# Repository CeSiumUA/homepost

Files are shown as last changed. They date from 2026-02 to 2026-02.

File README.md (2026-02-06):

# Homepost

Homepost is an ESP32-based home monitoring and automation hub that combines BLE tracking, environmental sensing, radiation monitoring, and MQTT integration into a single device.

## Features

- **BLE iBeacon Tracking**: Detects and tracks iBeacon devices for presence detection (e.g., phone tracking)
- **HTU21 Temperature & Humidity Sensor**: Monitors environmental conditions via I2C and publishes data via MQTT
- **Geiger Counter Integration**: Monitors radiation levels and publishes data via MQTT
- **WiFi Connectivity**:
  - Station mode for connecting to existing networks
  - SoftAP mode for initial configuration
  - Automatic reconnection with configurable retry intervals
- **HTTP Server**: Web-based configuration interface
- **MQTT Publishing**: Sends sensor data and presence information to an MQTT broker
- **NVS Storage**: Persistent storage for WiFi credentials, MQTT settings, and configuration

## Hardware Requirements

- ESP32 development board (4MB flash minimum)
- HTU21D temperature/humidity sensor (I2C, default: SDA=GPIO21, SCL=GPIO22)
- Geiger counter sensor (connected via GPIO)
- Power supply (USB or external)

> **Note**: A custom PCB design is available in the `hardware/` directory (KiCad 8 format).

## Software Dependencies

- ESP-IDF v5.5 or later
- FreeRTOS (included with ESP-IDF)

## Building the Project

### Prerequisites

1. Install ESP-IDF following the [official installation guide](https://docs.espressif.com/projects/esp-idf/en/latest/esp32/get-started/index.html)
2. Set up the ESP-IDF environment:

   ```bash
   . $HOME/esp/esp-idf/export.sh
   ```

### Configure

Configure the project using menuconfig:

```bash
idf.py menuconfig
```

Navigate to `homepost configuration` to customize:

- **BT Options**: Bluetooth device name, inquiry length
- **Scanner Options**: RSSI filters, iBeacon major/minor IDs, scan timeout
- **WiFi Configuration**: SoftAP credentials, reconnection settings
- **HTTP Server Configuration**: Port settings
- **Storage Configuration**: NVS keys for credentials

### Build

Build the project:

```bash
idf.py build
```

### Flash

Flash the firmware to your ESP32:

```bash
idf.py -p PORT flash
```

Replace `PORT` with your ESP32's serial port (e.g., `COM3` on Windows or `/dev/ttyUSB0` on Linux).

### Monitor

View the serial output:

```bash
idf.py -p PORT monitor
```

Or combine flash and monitor:

```bash
idf.py -p PORT flash monitor
```

## Configuration

### Initial Setup

1. On first boot, the device will create a WiFi access point named `HOMEPOST` (default password: `12345678`)
2. Connect to this network and access the web interface at `http://192.168.4.1`
3. Configure:
   - WiFi credentials for your home network
   - MQTT broker settings (address, port, credentials)
   - MQTT topic base (runtime configurable via web interface)
   - iBeacon tracking parameters
   - Publish intervals

### iBeacon Tracking

Configure the iBeacon major and minor IDs to match the devices you want to track:

- `HOMEPOST_SCAN_MAJOR_FILTER`: Major ID (default: 100)
- `HOMEPOST_SCAN_MINOR_FILTER`: Minor ID (default: 40004)
- `HOMEPOST_SCAN_TIMEOUT_MINUTES`: How long to wait before marking device as absent (default: 2 minutes)

### MQTT Topics

The device publishes to topics under the configured base topic:

- `{topic}/homepost_version`: Firmware version in JSON format (`{"version": "X.Y.Z"}`), published on MQTT connection
- `{topic}/phone_present`: Presence detection status (iBeacon tracking)
- `{topic}/phone_rssi`: BLE RSSI signal strength in JSON format (`{"rssi": -XX}`) when device is present
- `{topic}/temperature`: Temperature readings in JSON format (`{"temperature": XX.XX}`)
- `{topic}/humidity`: Humidity readings in JSON format (`{"humidity": XX.XX}`)
- `{topic}/geiger`: Geiger counter CPM (counts per minute) data

### HTU21 Temperature & Humidity Sensor

Configure the HTU21 sensor via menuconfig:

- `HOMEPOST_HTU21_TIMER_PERIOD_MS`: Reading interval (default: 60000ms / 1 minute)
- `HOMEPOST_HTU21_I2C_SDA_GPIO`: I2C SDA pin (default: GPIO 21)
- `HOMEPOST_HTU21_I2C_SCL_GPIO`: I2C SCL pin (default: GPIO 22)
- `HOMEPOST_HTU21_I2C_FREQ_HZ`: I2C clock frequency (default: 100kHz)

## Project Structure

```text
homepost/
├── CMakeLists.txt              # Project configuration
├── sdkconfig                   # Build configuration
├── main/
│   ├── main.c                  # Application entry point
│   ├── wifi.c                  # WiFi connection management
│   ├── http_server.c           # Web configuration interface
│   ├── ble_scanner.c           # BLE scanning functionality
│   ├── ble_ibeacon.c           # iBeacon protocol handling
│   ├── tracker_scanner.c       # Presence tracking logic
│   ├── geiger_counter.c        # Radiation sensor integration
│   ├── htu21_sensor.c          # HTU21 temperature/humidity sensor
│   ├── mqtt_connection.c       # MQTT client
│   ├── internal_storage.c      # NVS storage management
│   ├── ota_update.c            # OTA firmware update
│   └── Kconfig.projbuild       # Configuration menu
├── inc/                        # Header files
└── hardware/                   # KiCad PCB design files
    └── manufacturing/          # Gerber files for PCB fabrication
```

## OTA (Over-The-Air) Updates

Homepost supports automatic firmware updates from GitHub releases.

### Requirements

1. **Flash Size**: Requires 4MB flash (configured in `menuconfig` → `Serial flasher config` → `Flash size`)

2. **Partition Table**: Must use OTA-compatible partition layout. In `menuconfig`:
   - Navigate to `Partition Table`
   - Select `Two large size OTA partitions` (required for 4MB flash with OTA)

3. **Bootloader Rollback** (recommended): Enable automatic rollback on failed boot:
   - Navigate to `Bootloader config`
   - Enable `CONFIG_BOOTLOADER_APP_ROLLBACK_ENABLE`

### GitHub Release Format

When creating releases on GitHub:

- **Tag format**: `release-v{version}` (e.g., `release-v1.3.0`)
- **Asset filename**: `homepost-{version}.bin` (e.g., `homepost-1.3.0.bin`)

### OTA Configuration

Configure OTA settings via `menuconfig` → `homepost configuration` → `OTA Update Configuration`:

- `HOMEPOST_OTA_ENABLED`: Enable/disable OTA updates (default: enabled)
- `HOMEPOST_OTA_GITHUB_OWNER`: GitHub repository owner/organization
- `HOMEPOST_OTA_GITHUB_REPO`: Repository name (default: `homepost`)
- `HOMEPOST_OTA_CHECK_INTERVAL_HOURS`: Update check interval (default: 4 hours)
- `HOMEPOST_OTA_INITIAL_DELAY_SECONDS`: Delay before first check (default: 30 seconds)

### Manual Update

Access the web interface and use the "Firmware Update" section to:

- View current and available versions
- Check for updates manually
- Trigger an update installation

### API Endpoints

- `GET /check-update`: Returns JSON with version info
- `POST /trigger-update`: Triggers immediate update check and installation

## Hardware Design

The `hardware/` directory contains a complete KiCad 8 project for a custom Homepost PCB:

- **Schematic**: `homepost.kicad_sch`
- **PCB Layout**: `homepost.kicad_pcb`
- **Manufacturing Files**: `manufacturing/` directory contains Gerber files and drill files ready for PCB fabrication

## Troubleshooting

### WiFi Connection Issues

- Check the serial monitor for connection status
- Verify credentials are correct via the web interface
- The device will retry connection every 3 minutes by default

### MQTT Connection Problems

- Verify broker address and port are correct
- Check firewall settings on the broker
- Ensure credentials (if required) are properly configured

### BLE Scanning Not Working

- Verify the iBeacon major/minor IDs match your tracking device
- Check RSSI threshold if filtering is enabled
- Ensure Bluetooth (BLE advertising) is enabled on the tracking device

### HTU21 Sensor Not Working

- Verify I2C wiring: SDA to GPIO21, SCL to GPIO22 (default pins)
- Check that the sensor is powered (3.3V)
- Review serial monitor for I2C initialization errors
- Ensure no I2C address conflicts (HTU21 uses address 0x40)

## License

This project is provided as-is for personal and educational use.

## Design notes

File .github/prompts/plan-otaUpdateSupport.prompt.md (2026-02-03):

## Plan: Add OTA Update Support via GitHub Releases

Enable the ESP32 device to automatically check for firmware updates on GitHub releases, download newer versions over HTTPS, and self-update using ESP-IDF's native OTA capabilities. Firmware assets follow naming `homepost-{version}.bin`, tags follow `release-v{version}` format.

### Steps

1. **Switch partition table to OTA-compatible layout** in `menuconfig` → Partition Table → select "Factory app, two OTA definitions", and enable `CONFIG_BOOTLOADER_APP_ROLLBACK_ENABLE` under Bootloader config for automatic rollback on failed boot.

2. **Create [main/ota_update.c](main/ota_update.c) and [inc/ota_update.h](inc/ota_update.h)** implementing a FreeRTOS task that:
   - Waits 30 seconds after start for network stability, then waits for WiFi via `wifi_is_connected_to_internet()`
   - Fetches `https://api.github.com/repos/{owner}/{repo}/releases/latest` using `esp_http_client`
   - Parses JSON with `cJSON`: extracts `tag_name`, strips `release-v` prefix to get version (e.g., `release-v1.2.0` → `1.2.0`)
   - Finds asset URL matching `homepost-{version}.bin` from `assets[].browser_download_url`
   - Compares semver against `CONFIG_APP_PROJECT_VER`
   - On newer version: calls `tracker_scanner_stop()` to free heap, runs `esp_https_ota()` with `esp_crt_bundle_attach()` for GitHub's CA chain, then `esp_restart()`
   - Loops with `CONFIG_HOMEPOST_OTA_CHECK_INTERVAL_HOURS` delay (default 4 hours)

3. **Add OTA Kconfig options** in [main/Kconfig.projbuild](main/Kconfig.projbuild):
   - `CONFIG_HOMEPOST_OTA_ENABLED` (bool, default y)
   - `CONFIG_HOMEPOST_OTA_GITHUB_OWNER` (string)
   - `CONFIG_HOMEPOST_OTA_GITHUB_REPO` (string, default "homepost")
   - `CONFIG_HOMEPOST_OTA_CHECK_INTERVAL_HOURS` (int, default 4)
   - `CONFIG_HOMEPOST_OTA_INITIAL_DELAY_SECONDS` (int, default 30)
   
   Add required components to REQUIRES in [main/CMakeLists.txt](main/CMakeLists.txt): `esp_https_ota`, `esp_http_client`, `app_update`, `esp_crt_bundle`, `json`

4. **Integrate OTA task startup** in [main/main.c](main/main.c) by calling `ota_update_start_task()` after WiFi initialization, guarded by `#if CONFIG_HOMEPOST_OTA_ENABLED`, following existing task patterns with `configASSERT()`.

5. **Add HTTP endpoints** in [main/http_server.c](main/http_server.c):
   - `GET /check-update` → returns JSON `{"current_version": "1.2.0", "available_version": "1.2.1", "update_available": true}`
   - `POST /trigger-update` → stops BLE tracking, triggers immediate OTA, restarts on success
   - Update [main/web/index.html](main/web/index.html) with version display and "Check for Updates" button

6. **Update documentation**: Add OTA section to [README.md](README.md) explaining GitHub release requirements (tag format `release-v{version}`, asset naming `homepost-{version}.bin`), Kconfig options, rollback behavior. Update [.github/copilot-instructions.md](.github/copilot-instructions.md) with OTA architecture. Bump `CONFIG_APP_PROJECT_VER` in [sdkconfig](sdkconfig).

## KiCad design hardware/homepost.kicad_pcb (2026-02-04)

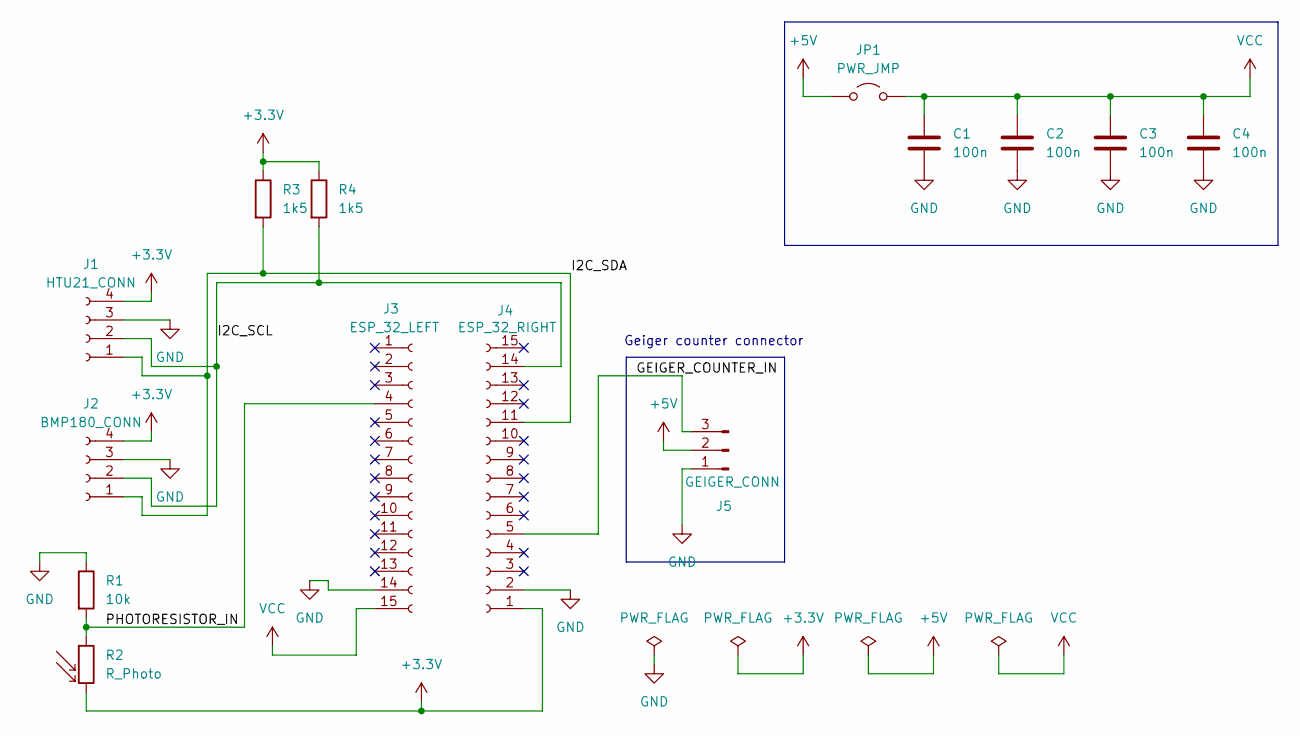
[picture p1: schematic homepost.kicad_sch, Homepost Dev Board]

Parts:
C1, C2, C3, C4: 100n; C_0402_1005Metric
J1: HTU21_CONN; PinSocket_1x04_P2.54mm_Vertical
J2: BMP180_CONN; PinSocket_1x04_P2.54mm_Vertical
J3: ESP_32_LEFT; PinSocket_1x15_P2.54mm_Vertical
J4: ESP_32_RIGHT; PinSocket_1x15_P2.54mm_Vertical
J5: GEIGER_CONN; PinHeader_1x03_P2.54mm_Vertical
JP1: PWR_JMP; PinHeader_1x02_P2.54mm_Vertical
R1: 10k; R_Axial_DIN0204_L3.6mm_D1.6mm_P5.08mm_Horizontal
R2: R_Photo; R_Axial_DIN0204_L3.6mm_D1.6mm_P5.08mm_Horizontal
R3, R4: 1k5; R_0402_1005Metric

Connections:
+3.3V: J1.4, J2.4, J4.1, R2.2, R3.1, R4.1
+5V: J5.2, JP1.1 (A)
/GEIGER_COUNTER_IN: J4.5, J5.3
/I2C_SCL: J1.2, J2.2, J4.14, R4.2
/I2C_SDA: J1.1, J2.1, J4.11, R3.2
/PHOTORESISTOR_IN: J3.4, R1.2, R2.1
GND: C1.2, C2.2, C3.2, C4.2, J1.3, J2.3, J3.14, J4.2, J5.1, R1.1
VCC: C1.1, C2.1, C3.1, C4.1, J3.15, JP1.2 (B)

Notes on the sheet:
Geiger counter connector

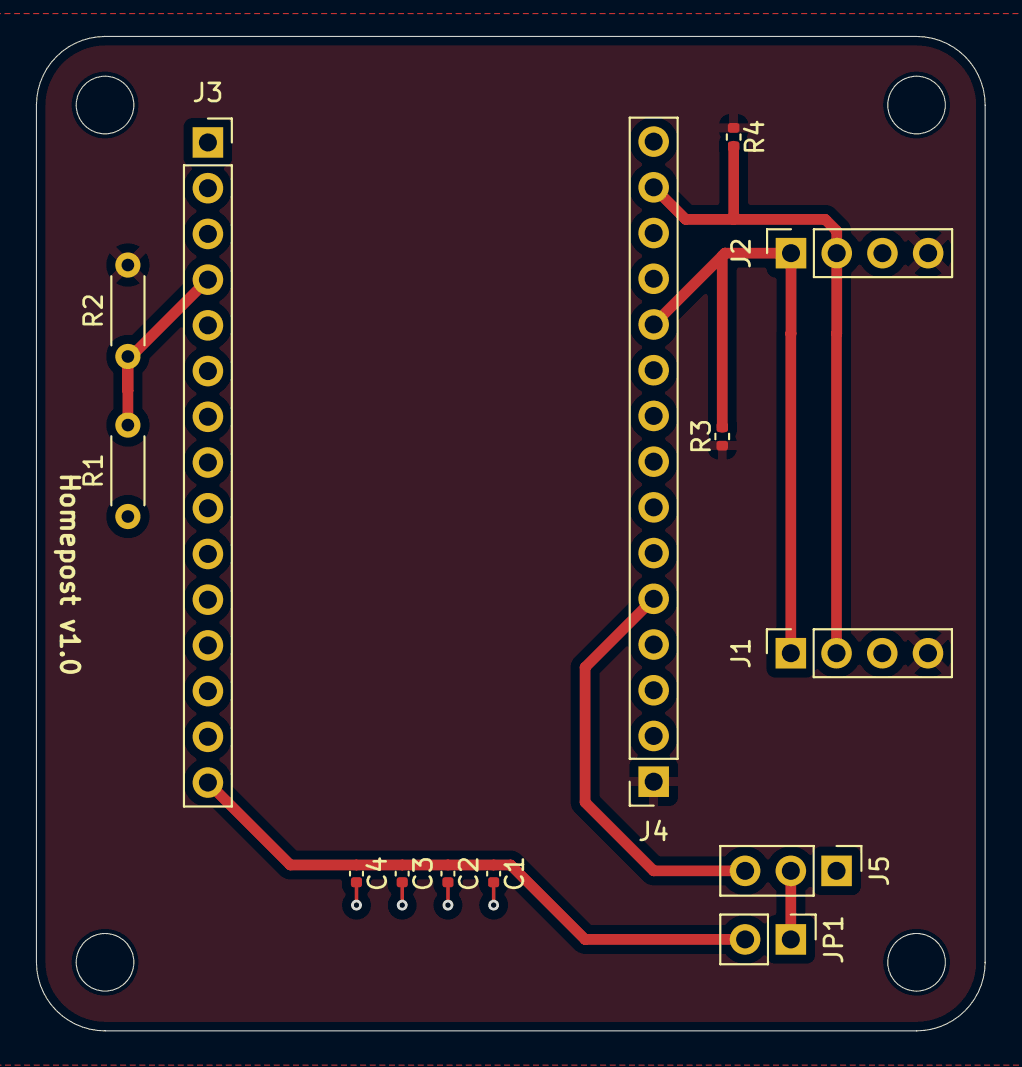
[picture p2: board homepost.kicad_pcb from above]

Board: 2 copper layers, 52.7 x 55.2 mm, 14 parts (0 on the bottom side), 8 nets.

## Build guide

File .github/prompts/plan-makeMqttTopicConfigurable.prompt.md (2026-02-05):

## Plan: Make MQTT Topic Runtime Configurable

Move MQTT topic from compile-time Kconfig to runtime configuration via web interface and NVS storage. The NVS storage functions already exist—main work involves updating the web form, HTTP handler with validation, and refactoring all components to build topic strings dynamically at initialization time.

### Steps

1. **Add MQTT topic input field** to [main/web/index.html](main/web/index.html) within the MQTT configuration form — simple text input named `mqtt-topic`, no default value display needed.

2. **Update POST handler** in [http_server.c](main/http_server.c) `mqtt_setup_post_handler` to parse `mqtt-topic` field, validate it (reject empty strings, check for invalid MQTT wildcard characters `+` and `#`), and call existing `internal_storage_save_mqtt_topic()`. Return HTTP 400 with error message if validation fails.

3. **Add topic provider function** in [mqtt_connection.c](main/mqtt_connection.c) — create `mqtt_connection_get_base_topic(char *topic_out)` that loads from NVS via `internal_storage_get_mqtt_topic()`, falling back to `CONFIG_HOMEPOST_MQTT_TOPIC` if not preserved. Expose via [mqtt_connection.h](inc/mqtt_connection.h).

4. **Refactor [mqtt_connection.c](main/mqtt_connection.c)** — change `version_message` topic from static literal to a 100-byte static buffer, populate via `snprintf(buf, size, "%s/homepost_version", base_topic)` in `mqtt_connection_publish_version()` before first use.

5. **Refactor [tracker_scanner.c](main/tracker_scanner.c)** — add static topic buffer, build `"{base}/phone_present"` in `tracker_scanner_start_task()` before publishing.

6. **Refactor [htu21_sensor.c](main/htu21_sensor.c)** — add static buffers for temperature and humidity topics, build `"{base}/temperature"` and `"{base}/humidity"` in `htu21_sensor_start()`.

7. **Refactor [geiger_counter.c](main/geiger_counter.c)** — add static topic buffer, build `"{base}/radiation"` in `geiger_counter_start()`.

8. **Update documentation** in [README.md](README.md) and [.github/copilot-instructions.md](.github/copilot-instructions.md) to note MQTT topic is now runtime-configurable via web interface.

9. **Bump version** in [sdkconfig](sdkconfig) `CONFIG_APP_PROJECT_VER`. Bump just a patch version, don't change major/minor.

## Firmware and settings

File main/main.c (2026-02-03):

#include <stdio.h>
#include "internal_storage.h"
#include "tracker_scanner.h"
#include "wifi.h"
#include "http_server.h"
#include "geiger_counter.h"
#include "htu21_sensor.h"
#include "esp_log.h"
#include <esp_timer.h>

#if CONFIG_HOMEPOST_OTA_ENABLED
#include "ota_update.h"
#endif

static void wifi_reconnection_timer_cb(void *arg);

static esp_timer_handle_t wifi_reconnection_timer;

static const esp_timer_create_args_t wifi_reconnection_timer_args = {
    .callback = &wifi_reconnection_timer_cb,
};

static const char *TAG = __FILE__;

static void wifi_reconnection_timer_cb(void *arg)
{
    bool reconnection_succeeded = false;
    reconnection_succeeded = wifi_connect_sta(false);
    if(reconnection_succeeded){
        ESP_LOGI(TAG, "WiFi reconnection succeeded");
        esp_timer_stop(wifi_reconnection_timer);
    }
    else{
        ESP_LOGI(TAG, "WiFi reconnection failed");
    }
}

void app_main(void)
{
    bool connected_to_ap = false;
    internal_storage_init();

    wifi_init();

    if(internal_storage_check_wifi_credentials_preserved()){
        connected_to_ap = wifi_connect_sta(false);
        if (!connected_to_ap){
            ESP_LOGI(TAG, "WiFi connection failed, starting reconnection timer");
            esp_timer_create(&wifi_reconnection_timer_args, &wifi_reconnection_timer);
            esp_timer_start_periodic(wifi_reconnection_timer, CONFIG_HOMEPOST_WIFI_RECONNECTION_TIMER_PERIOD_US);
        }
        else{
            ESP_LOGI(TAG, "WiFi connection succeeded");
        }
    }
    
    if(!connected_to_ap){
        ESP_LOGI(TAG, "WiFi credentials not found in NVS, starting softAP mode");
        wifi_start_softap();
    }

    http_server_init();
    http_server_start();

    tracker_scanner_start_task();
    mqtt_connection_start_task();
    geiger_counter_start();
    htu21_sensor_start();

#if CONFIG_HOMEPOST_OTA_ENABLED
    ota_update_start_task();
#endif
}

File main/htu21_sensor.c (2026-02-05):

#include "htu21_sensor.h"
#include "mqtt_connection.h"
#include <driver/i2c_master.h>
#include <esp_timer.h>
#include <esp_log.h>
#include <string.h>
#include <freertos/FreeRTOS.h>
#include <freertos/task.h>

#define HTU21_I2C_ADDR                  0x40
#define HTU21_CMD_TEMP_HOLD             0xE3
#define HTU21_CMD_HUMIDITY_HOLD         0xE5
#define HTU21_CMD_TEMP_NOHOLD           0xF3
#define HTU21_CMD_HUMIDITY_NOHOLD       0xF5
#define HTU21_CMD_SOFT_RESET            0xFE

static const char *TAG = __FILE__;

static i2c_master_bus_handle_t i2c_bus_handle = NULL;
static i2c_master_dev_handle_t htu21_dev_handle = NULL;

static esp_timer_handle_t htu21_timer;

static char temperature_payload[32];
static char humidity_payload[32];
static char temperature_topic[100];
static char humidity_topic[100];

static struct mqtt_connection_message_t temperature_message = {
    .topic = temperature_topic,
    .payload = temperature_payload,
    .qos = 0
};

static struct mqtt_connection_message_t humidity_message = {
    .topic = humidity_topic,
    .payload = humidity_payload,
    .qos = 0
};

static esp_err_t htu21_read_temperature(float *temperature)
{
    uint8_t cmd = HTU21_CMD_TEMP_NOHOLD;
    uint8_t data[2];
    esp_err_t ret;

    ret = i2c_master_transmit(htu21_dev_handle, &cmd, 1, 1000);
    if (ret != ESP_OK) {
        ESP_LOGE(TAG, "Failed to send temperature command: %s", esp_err_to_name(ret));
        return ret;
    }

    vTaskDelay(pdMS_TO_TICKS(85));

    ret = i2c_master_receive(htu21_dev_handle, data, sizeof(data), 1000);
    if (ret != ESP_OK) {
        ESP_LOGE(TAG, "Failed to receive temperature data: %s", esp_err_to_name(ret));
        return ret;
    }

    uint16_t raw_temp = (data[0] << 8) | data[1];
    *temperature = -46.85 + 175.72 * (raw_temp / 65536.0);

    return ESP_OK;
}

static esp_err_t htu21_read_humidity(float *humidity)
{
    uint8_t cmd = HTU21_CMD_HUMIDITY_NOHOLD;
    uint8_t data[2];
    esp_err_t ret;

    ret = i2c_master_transmit(htu21_dev_handle, &cmd, 1, 1000);
    if (ret != ESP_OK) {
        ESP_LOGE(TAG, "Failed to send humidity command: %s", esp_err_to_name(ret));
        return ret;
    }

    vTaskDelay(pdMS_TO_TICKS(50));

    ret = i2c_master_receive(htu21_dev_handle, data, sizeof(data), 1000);
    if (ret != ESP_OK) {
        ESP_LOGE(TAG, "Failed to receive humidity data: %s", esp_err_to_name(ret));
        return ret;
    }

    uint16_t raw_humidity = (data[0] << 8) | data[1];
    *humidity = -6.0 + 125.0 * (raw_humidity / 65536.0);

    return ESP_OK;
}

static void htu21_timer_cb(void *arg)
{
    float temperature, humidity;
    esp_err_t ret;

    ret = htu21_read_temperature(&temperature);
    if (ret == ESP_OK) {
        ESP_LOGI(TAG, "Temperature: %.2f C", temperature);
        memset(temperature_payload, 0, sizeof(temperature_payload));
        int len = snprintf(temperature_payload, sizeof(temperature_payload), 
                          "{\"temperature\": %.2f}", temperature);
        if (len > 0 && len < sizeof(temperature_payload)) {
            if (mqtt_connection_put_publish_queue(&temperature_message) != ESP_OK) {
                ESP_LOGE(TAG, "Failed to enqueue temperature message");
            }
        } else {
            ESP_LOGE(TAG, "Failed to format temperature payload");
        }
    } else {
        ESP_LOGE(TAG, "Failed to read temperature, skipping publish");
    }

    ret = htu21_read_humidity(&humidity);
    if (ret == ESP_OK) {
        ESP_LOGI(TAG, "Humidity: %.2f %%", humidity);
        memset(humidity_payload, 0, sizeof(humidity_payload));
        int len = snprintf(humidity_payload, sizeof(humidity_payload), 
                          "{\"humidity\": %.2f}", humidity);
        if (len > 0 && len < sizeof(humidity_payload)) {
            if (mqtt_connection_put_publish_queue(&humidity_message) != ESP_OK) {
                ESP_LOGE(TAG, "Failed to enqueue humidity message");
            }
        } else {
            ESP_LOGE(TAG, "Failed to format humidity payload");
        }
    } else {
        ESP_LOGE(TAG, "Failed to read humidity, skipping publish");
    }
}

static const esp_timer_create_args_t htu21_timer_args = {
    .callback = &htu21_timer_cb,
};

static esp_err_t htu21_init(void)
{
    uint8_t cmd = HTU21_CMD_SOFT_RESET;
    esp_err_t ret;

    ret = i2c_master_transmit(htu21_dev_handle, &cmd, 1, 1000);
    if (ret != ESP_OK) {
        ESP_LOGE(TAG, "Failed to reset HTU21: %s", esp_err_to_name(ret));
        return ret;
    }

    vTaskDelay(pdMS_TO_TICKS(20));
    ESP_LOGI(TAG, "HTU21 sensor initialized successfully");

    return ESP_OK;
}

void htu21_sensor_start(void)
{
    esp_err_t ret;

    // Build MQTT topics from base topic
    char base_topic[64];
    if (mqtt_connection_get_base_topic(base_topic, sizeof(base_topic)) == ESP_OK) {
        snprintf(temperature_topic, sizeof(temperature_topic), "%s/temperature", base_topic);
        snprintf(humidity_topic, sizeof(humidity_topic), "%s/humidity", base_topic);
    } else {
        ESP_LOGE(TAG, "Failed to get base topic, using default");
        snprintf(temperature_topic, sizeof(temperature_topic), "%s/temperature", CONFIG_HOMEPOST_MQTT_TOPIC);
        snprintf(humidity_topic, sizeof(humidity_topic), "%s/humidity", CONFIG_HOMEPOST_MQTT_TOPIC);
    }

    ESP_LOGI(TAG, "Starting HTU21 sensor on I2C bus (SDA: %d, SCL: %d, freq: %d Hz)",
             CONFIG_HOMEPOST_HTU21_I2C_SDA_GPIO, CONFIG_HOMEPOST_HTU21_I2C_SCL_GPIO,
             CONFIG_HOMEPOST_HTU21_I2C_FREQ_HZ);

    i2c_master_bus_config_t bus_config = {
        .i2c_port = I2C_NUM_0,
        .sda_io_num = CONFIG_HOMEPOST_HTU21_I2C_SDA_GPIO,
        .scl_io_num = CONFIG_HOMEPOST_HTU21_I2C_SCL_GPIO,
        .clk_source = I2C_CLK_SRC_DEFAULT,
        .glitch_ignore_cnt = 7,
        .flags.enable_internal_pullup = true,
    };

    ret = i2c_new_master_bus(&bus_config, &i2c_bus_handle);
    if (ret != ESP_OK) {
        ESP_LOGE(TAG, "Failed to create I2C bus: %s", esp_err_to_name(ret));
        return;
    }

    i2c_device_config_t dev_config = {
        .dev_addr_length = I2C_ADDR_BIT_LEN_7,
        .device_address = HTU21_I2C_ADDR,
        .scl_speed_hz = CONFIG_HOMEPOST_HTU21_I2C_FREQ_HZ,
    };

    ret = i2c_master_bus_add_device(i2c_bus_handle, &dev_config, &htu21_dev_handle);
    if (ret != ESP_OK) {
        ESP_LOGE(TAG, "Failed to add HTU21 device: %s", esp_err_to_name(ret));
        i2c_del_master_bus(i2c_bus_handle);
        return;
    }
    ESP_LOGI(TAG, "HTU21 device added to I2C bus at address 0x%02X", HTU21_I2C_ADDR);

    ret = htu21_init();
    if (ret != ESP_OK) {
        ESP_LOGE(TAG, "HTU21 initialization failed, sensor readings may be unreliable");
    }

    ret = esp_timer_create(&htu21_timer_args, &htu21_timer);
    if (ret != ESP_OK) {
        ESP_LOGE(TAG, "Failed to create timer: %s", esp_err_to_name(ret));
        i2c_master_bus_rm_device(htu21_dev_handle);
        i2c_del_master_bus(i2c_bus_handle);
        return;
    }
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

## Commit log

2025-03-02 Initialize sample project with basic structure and Docker support
2025-03-14 Update scanner configuration and implement RSSI filtering in tracker scanner
2025-03-15 Enhance tracker scanner with RSSI filtering and task handle initialization
2025-03-16 Added WiFi with provisioning (http server) (#2)
    * Add WiFi credentials storage configuration and implement related functions
    * Implement WiFi credentials management and HTTP server initialization
    * Fix WiFi connection logic to start soft AP when credentials are not preserved
    [main.c]
2025-08-19 5 add mqtt broker connection (#6)
    * Add MQTT configuration and storage support
    * Refactor HTTP server URIs and update web forms for WiFi and MQTT configuration
    * Add WiFi reconnection timer configuration and implement reconnection logic
    * Implement MQTT connection handling and configuration options
    * Add MQTT publish event handling and message publishing logic
    * Implement MQTT configuration handling and add MQTT connection management functions
    * Change TAG variable to static in main.c and mqtt_connection.c for better encapsulation
    * Add MQTT client ID configuration to HTTP server and MQTT connection handling
    * Update Docker args in CI workflow to ensure container removal
    [main.c]
2025-08-19 Add geiger_counter functionality and integrate with main application (#8)
    * Add geiger_counter functionality and integrate with main application
    * Add Geiger counter configuration and update MQTT publish queue function
    * Update Geiger counter input pin definition and ISR handler; adjust timer period for improved performance
    * Update Geiger counter configuration: disable pull-up resistor and extend timer period to 60 seconds
    * Fix average CPM calculation to ensure proper floating-point division
    [geiger_counter.c, main.c]
2025-08-20 9 add mqtt message publishing for device presence (#10)
    * Update radiation payload size and change MQTT topic to living_room/radiation
    * Reduce MQTT and tracker scanner task stack sizes to optimize memory usage
    * Update MQTT topic configuration and enhance tracker scanner functionality
    * Add scan timeout configuration and update scanner timeout logic
2026-01-31 Add HTU21 sensor support with configuration options and MQTT integration (#19)
    * Add HTU21 sensor support with configuration options and MQTT integration
    * Add cleanup step to GitHub Actions workflow and update cSpell dictionary
    * Add logging for temperature and humidity readings in HTU21 sensor
    * Refactor HTU21 sensor commands to use non-hold modes and adjust data buffer sizes
2026-02-01 Updated documentation (#23)
    * Add documentation for version handling and update requirements
    * Update README and documentation to include HTU21 sensor details and increment project version to 1.2.0
2026-02-04 29 add hardware design files (#30)
    * Add manufacturing files for homepost project
    - Created homepost-job.gbrjob file containing board specifications, design rules, and material stackup.
    - Added homepost.drl file with drill specifications for various hole sizes and positions.
    * Update SDK configuration for versioning and initialization
    * Updated README.md
    * REnamed configuration section to avoid duplication
    [homepost-B_Cu.gbr, homepost-B_Mask.gbr, homepost-B_Paste.gbr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]
2026-02-05 Made MQTT topic configurable at runtime via web interface (#34)
    * make MQTT topic configurable at runtime via web interface and NVS storage
    * hide update button by default and apply consistent styling
    * add input validation for WiFi and MQTT connection forms
2026-02-05 40 fix version loading (#41)
    * Revert "Remove automatic update check on page load (#39)"
    This reverts commit fe648b40de8ebc1b8dfaf0d525dd5a4952fa6721.
    * Revert "Implement synchronous check for updates via GitHub releases API (#37)"
    This reverts commit 67efffa9936355a10b7dea973bd5d72c5c8110c7.
    * Update version number to 1.4.6 and modify button display for firmware update
